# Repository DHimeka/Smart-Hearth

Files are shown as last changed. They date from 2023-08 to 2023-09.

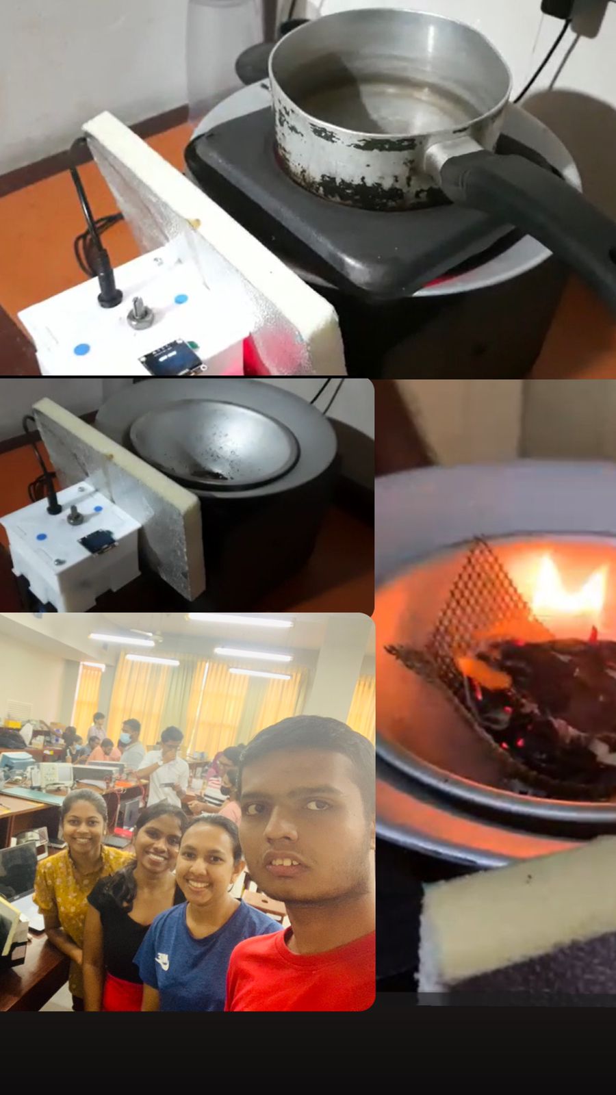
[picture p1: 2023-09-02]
images/Intro.jpg

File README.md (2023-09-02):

# Smart Hearth Project 

Smart Hearth Logo

In the EN2091 Laboratory Practice and Projects during our third semester, our team successfully designed and developed a fully functional function generator with laboratory-grade capabilities. By harnessing the potential of basic electronic components, we achieved precise waveform generation and control using opamps, transistors, resistors, capacitors, and potentiometers. Our research and design enabled the implementation of analog electronic calculations, resulting in the generation of sine, square, triangular, sawtooth, and PWM waveforms with accurate frequency control from 20Hz to 20kHz. A crucial aspect of the project was robust control over amplitude and DC, which we accomplished through feedback mechanisms and precise opamp configurations, allowing users to manipulate output voltage from 0V to 20V. Despite facing various challenges during the project, including iterative circuit refinement and enclosure and PCB fabrication, the final outcome was impressive. The fully functional function generator showcased a harmonious fusion of creative circuit design and engineering to its finest. We take immense pride in this accomplishment, confident in the potential of our function generator to make a significant impact in laboratory settings and beyond.

## Table of Contents
- [Introduction](#introduction)
  - [Product Overview](#product-overview)
  - [Key Components](#key-components)
- [Development](#development)
  - [Circuit Design](#circuit-design)
  - [Arduino Implementation](#arduino-implementation)
  - [Breadboard Implementation](#breadboard-implementation)
  - [PCB Design](#pcb-design)
  - [Enclosure Design](#enclosure-design)
- [List of Components](#list-of-components)
- [UI and UX](#ui-and-ux)
- [Testing and Results](#testing-and-results)
- [Further Improvements](#further-improvements)
- [Discussions](#discussions)
- [Bibliography](#bibliography)

## Introduction

### Product Overview

The Smart Hearth project is designed to address the challenges faced by households relying on traditional hearths for cooking. It introduces a system that automates temperature regulation, improving the cooking experience and reducing user intervention. The core components of the device include the ATmega328P microcontroller, MAX6675 Temperature Sensor, OLED display, potentiometer, DC fan, and more.

### Key Components

- **ATmega328-PU:** This high-performance microcontroller forms the heart of the system, controlling various aspects of the Smart Hearth's functionality.

- **MAX6675 Temperature Sensor:** Responsible for accurately measuring the temperature of the hearth, ensuring precise control.

- **OLED Display:** Provides users with real-time information about the selected temperature range and system status.

- **Potentiometer:** Enables users to choose from six predefined temperature ranges, enhancing user-friendliness.

- **DC Fan:** Regulates the heat by adjusting its speed based on the temperature sensor readings.

## Development

### Circuit Design

The project began with circuit design using the EasyEDA software, ensuring the proper connections among components. The schematic design encompassed various elements, including temperature sensors, microcontrollers, and motor driver modules.

### Arduino Implementation

The initial implementation involved testing the circuit with LED bulbs to assess brightness control based on temperature levels. Subsequently, a DC fan was integrated into the circuit, followed by the addition of a buzzer to alert users of abnormalities. The OLED display was also incorporated to visualize temperature settings.

### Breadboard Implementation

To move from Arduino testing to a standalone system, the circuit was replicated on a standalone ATmega328-PU microcontroller. This step ensured the transition to a more compact and functional setup.

### PCB Design

Altium software was used for designing a single-layer PCB, considering factors like trace width and power requirements. The design aimed to optimize the circuit layout for efficient performance.

### Enclosure Design

The physical enclosure for the Smart Hearth underwent careful consideration. A conical shape was chosen for the hearth's opening to facilitate efficient heat transfer. Aluminum was selected as the primary material for its durability and resistance to cracking. A wooden box surrounded the aluminum structure to prevent user harm from the heated material. The design also featured openings for the fan, LCD, potentiometer, and temperature sensor.

## List of Components

- **ATmega328-PU:** The microcontroller at the heart of the system.
- **MAX6675 Temperature Sensor:** Responsible for precise temperature measurements.
- **OLED Display:** Provides real-time information to users.
- **Potentiometer:** Enables user selection of temperature ranges.
- **DC Fan:** Regulates heat by adjusting speed.
- **L9110 Motor Driver Module:** Controls the fan's speed.
- **12V Power Pack:** Provides power to the system.

## UI and UX

The user interface consists of an OLED display and a potentiometer. Users can select from six temperature ranges, each represented by a specific color on the potentiometer. The selected range is displayed on the OLED, making it easy for users to monitor and adjust settings.

## Testing and Results

Extensive testing was conducted to ensure the system's functionality. Individual component testing was performed using Arduino, including LED brightness control, fan speed adjustment, buzzer functionality, and OLED output validation. The system successfully regulated temperature within selected ranges.

## Further Improvements

Future enhancements to the Smart Hearth system could include:

- Smoke disposal system for improved air quality.
- Development of a mobile app for remote control and monitoring.
- Enhanced product packaging for user convenience and safety.

## Discussions

During development, several challenges were addressed, including:

- Material selection for the hearth enclosure.
- Overlapping OLED display terms.
- Determining the optimal time for the buzzer to activate.

## Bibliography

- [Guide for I2C OLED Display with Arduino](https://randomnerdtutorials.com/guide-for-oled-display-with-arduino/)
- [Spherical and Cylindrical Pressure Vessels](https://www.wermac.org/equipment/pressurevessel.html)
- [Getting Started With the ATMega328P](https://www.instructables.com/Getting-Started-With-the-ATMega328P/)
- [Temperature based Fan Speed Control](https://create.arduino.cc/projecthub/embeddedlab786/temperature-based-fan-speed-control-945f9d)
- [WHEN TO USE ALUMINUM VS STAINLESS STEEL](https://www.kloecknermetals.com/blog/when-to-use-aluminum-vs-stainless-steel/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,over%20steel%20in%20cold%20temperatures.)
- [The Laws of Thermo-Culinary Dynamics](https

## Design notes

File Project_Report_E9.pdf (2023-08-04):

## Department of Electronic & Telecommunication Engineering

## University of Moratuwa

# Hearth

### Group EN09

200222K | HIMEKA S.H.D.
200232P | INDRAPALA S.A.
200239T | JATHURSHAN S.
200242V | JAYAKODY J.A.A.U.

This report is submitted for module EN1190

07th October 2022

## Abstract

The hearth regulates the temperature of the fire as per the user requirement by using the reading taken from the temperature sensor and regulating the DC fan speed accordingly. The hearth has a user interface which allows the user to turn a knob to their required temperature range and the selected range will be displayed on the OLED. Additionally, the hearth also has a buzzer going off if there are any abnormalities when functioning. The enclosure for the hearth was designed using SolidWorks and attention was given to the materials employed. The PCB was designed using Altium.

## Contents

### Introduction

The hearth takes into consideration the input temperature range by the user as well as the
current | temperature | reading | from | the
temperature sensor and will change the fan speed in order to bring the temperature into the users’ temperature range. The main components of the device are,
- ATmega328P-PU
- MAX6675 Temperature Sensor
- OLED
- 100K Potentiometer
- 12V DC fan
- L9110 Motor Driver Module
- 12V Power Pack

The device gives the user an option of 6 temperature ranges and has a buzzer and a display to notify the user of the selected temperature range and if there is an issue in the functionality.

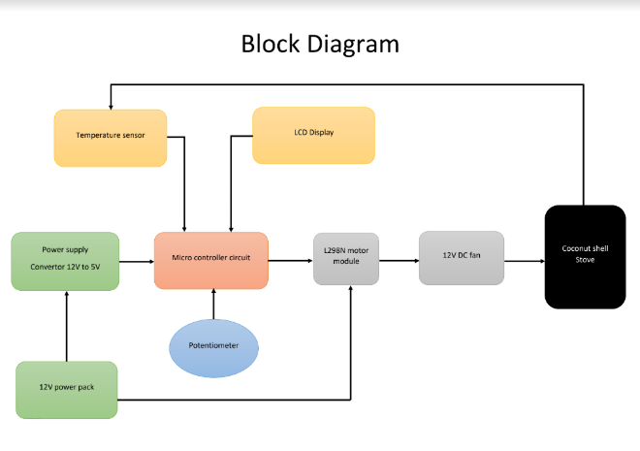
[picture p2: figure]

Figure 1.1: Block Diagram of the Device

### Product Description

Design Idea

Given the shortage of gas cylinders and the hike of gas cylinder prices in the recent past in Sri Lanka, most people have been turning to using electric induction cookers or hearths. Since electricity prices as well as induction cooker prices have also increased, most households have been using traditional hearths.

Motivation

However, these hearths have potential to be improved to make the cooking experience more user friendly. The existing market products can be seen to lack the following features,

- User must keep blowing into the flame to control the flame. Even the hearths with DC fans have an unreliable increase and reduction in temperatures such that the user must consistently be present to adjust fan speeds.
- Soot depositions on cooking utensils and the stove.
- Cleaning the ash leftovers after usage.
- Smokes released are disturbing.

Who Benefits?

Our device would cater to most lower to middle class households as it could reduce the costs associated with gas cylinders as well as electricity.

### Product Idea Validation

Hearths have a lot of room for improvement. However, the main problem we chose to focus on was the fact that the user must be in constant vicinity of the hearth to ensure that the heat from the fire is regulated at the needed level. This would be a waste of time for the consumer.

Therefore, our solution was to build a hearth with a DC fan which would regulate the heat in the needed level once the user has input their requirement.

To ensure that this was a requirement of our target market we conducted a survey through which we collected the following data.

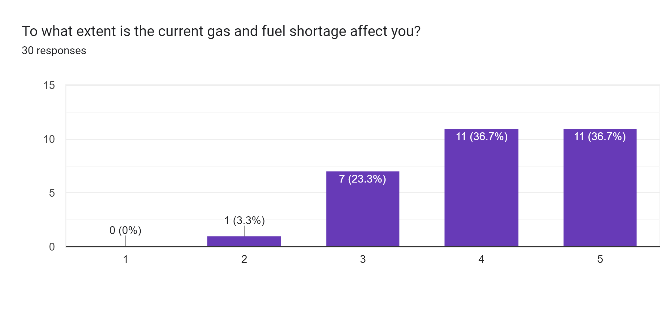
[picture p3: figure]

Figure 3.1: The extent to which users were affected by the gas shortage.

As seen by Figure 3.1, more than 50% of users were highly affected by the gas shortage. Therefore, an alternative for gas cookers is necessary.

Figure 3.2: Will the user buy our product?

On explaining the product, we had in mind, most users showed positive responses whereas a few were unsure but none of the users believed that the product was not needed.

Figure 3.3: User needs.

We then took this opportunity to check what the user expected of this product and on designing the product we took into consideration most of these factors.

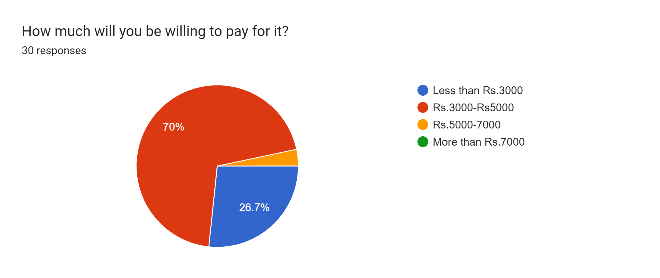
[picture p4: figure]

Figure 3.4: Product cost

Finally, we asked the users what cost they would be willing to incur for this product. As per Figure 3.4, the price range was determined to be between Rs 3,000 and Rs 5,000. However, this survey was conducted approximately 2 months prior and did not take into consideration the import bans as well as the inflation. Currently, the market price for similar products range between Rs 7,000 and Rs 11,000. Therefore, the price for the product may have to be reconsidered to around Rs 8,000 or more.

### Development

The development of this project was done in four stages. They are,

1. Circuit Design
2. Arduino Implementation
3. Breadboard Implementation with the

Microcontroller

Circuit Design

Initially a schematic with all the circuit components was built using the EasyEDA software. Afterwards, the connections between each component were made.

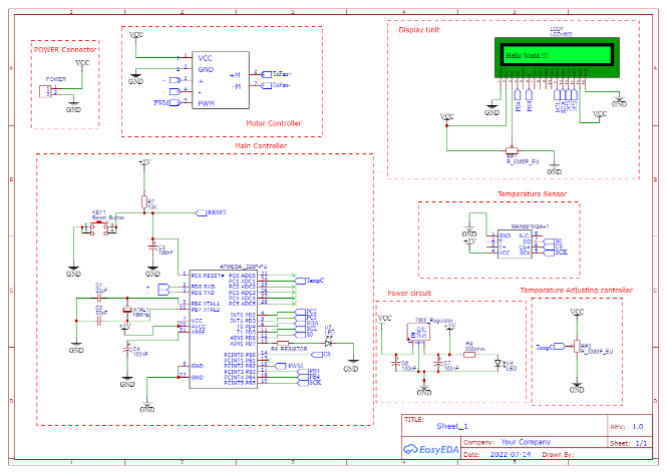
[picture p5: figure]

Figure 4.1: Circuit components

Arduino Implementation

Once all the circuit connections were made, the circuit was implemented on an Arduino step by step to check its functionality.

Initially, instead of using a DC fan, we placed LED bulbs in order to check whether the brightness can be changed for different temperature levels.

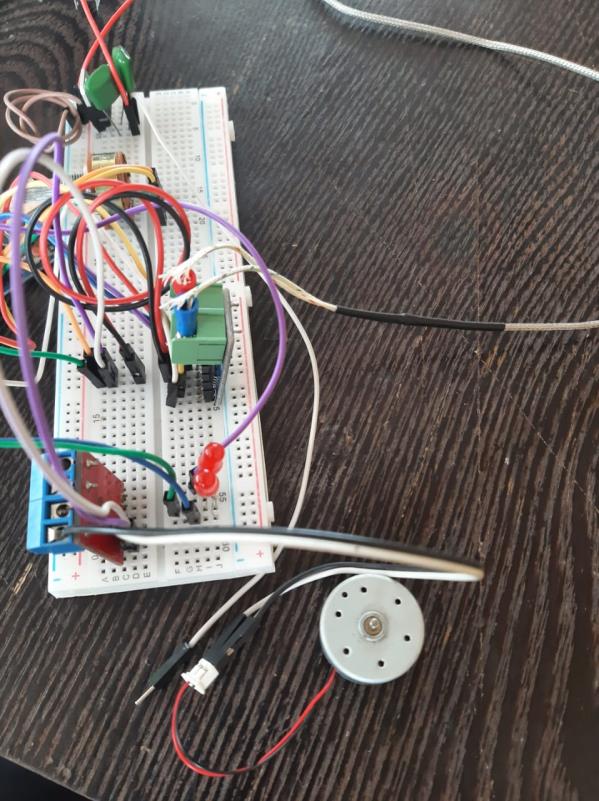
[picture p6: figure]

Figure 4.2: Testing using LED’s

After this proved to be successful, we next added the DC fan to the circuit as well.

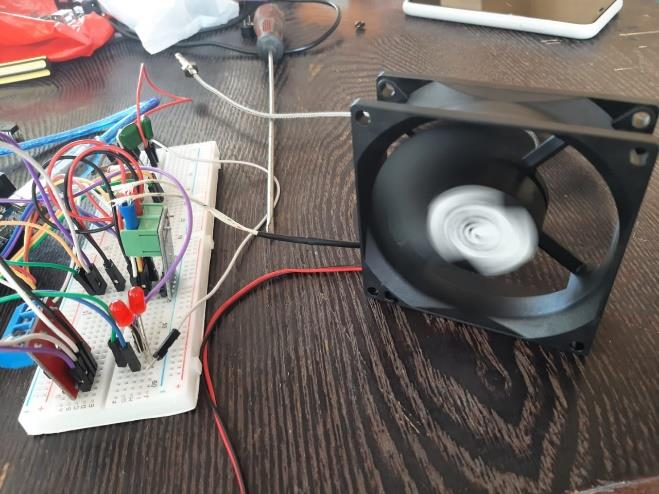
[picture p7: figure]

Figure 4.3: Testing the fan

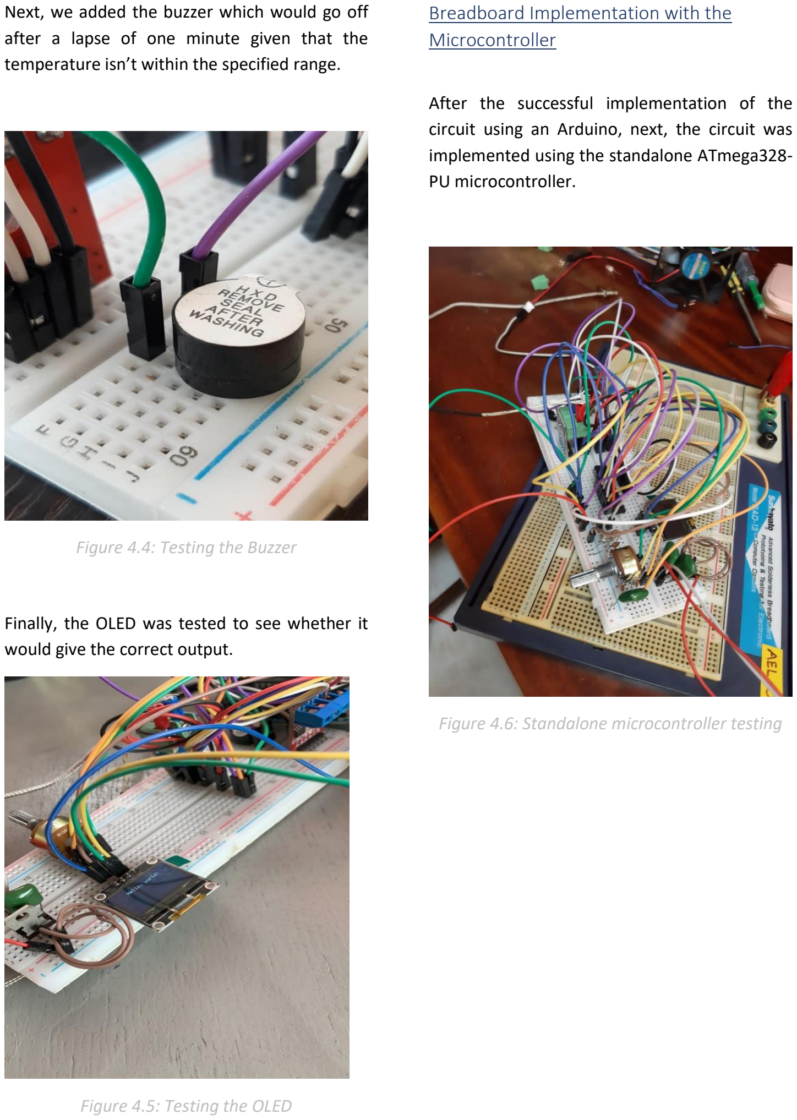
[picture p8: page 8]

Next, we added the buzzer which would go off after a lapse of one minute given that the temperature isn’t within the specified range.

Figure 4.4: Testing the Buzzer

Finally, the OLED was tested to see whether it would give the correct output.

Figure 4.5: Testing the OLED

Breadboard Implementation with the Microcontroller

After the successful implementation of the circuit using an Arduino, next, the circuit was implemented using the standalone ATmega328-PU microcontroller.

Figure 4.6: Standalone microcontroller testing

### PCB Design

PCB design was done using Altium software. In the schematic design, all the components and connections were done according to our circuit design and Arduino implementation. The design was a single layer PCB.

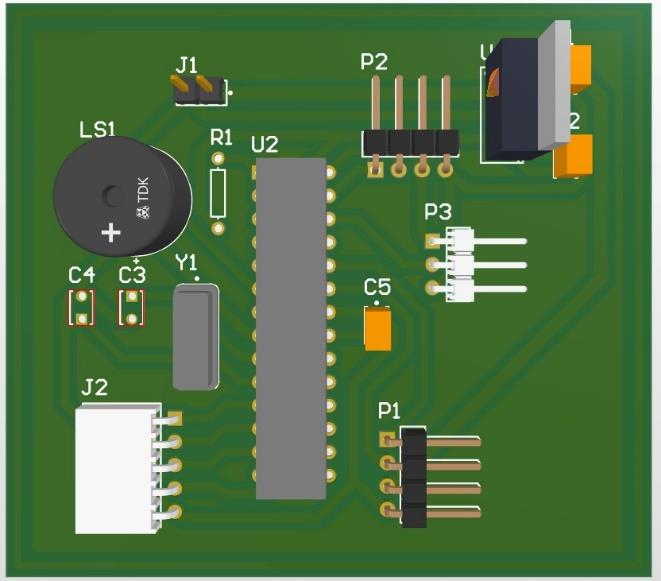
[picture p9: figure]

Figure 5.1: 3D view of the PCB

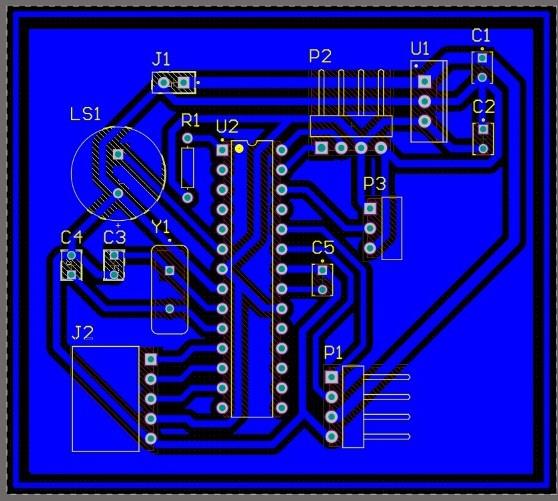
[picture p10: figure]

Figure 5.2: PCB design

For the 12V power supply 1.5mm trace width was selected and for the 5V power supply 1mm trace width was selected. The ground had a 1.5mm trace width and the signal lines had a 0.8mm trace width.

These measurements were made taking into
consideration | the | power | and | current
consumption of the circuit.

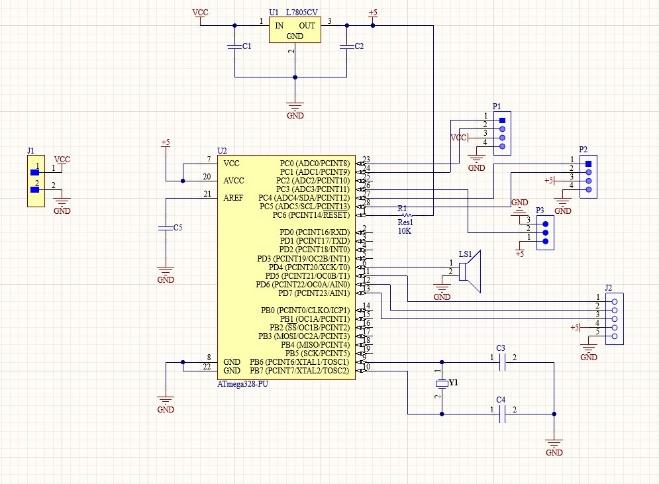
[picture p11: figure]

Figure 5.3: Schematic

### Enclosure Design

Considering the existing models in the industry, we made an initial sketch on how we wanted the hearth to look like.

To ensure that the cooking pots fit perfectly and to ensure efficient heat transfer, the opening of the hearth was decided to be conical in shape.

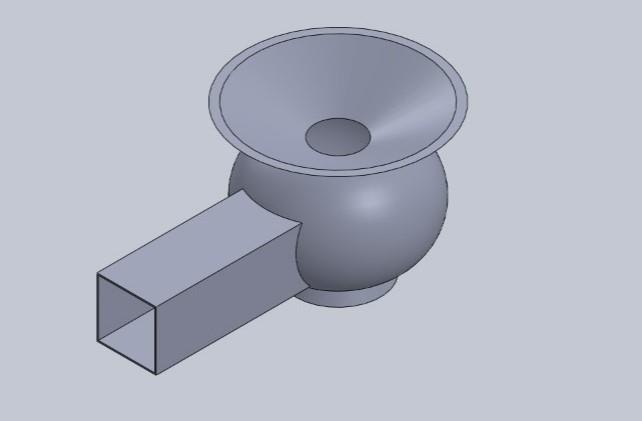
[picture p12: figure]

Figure 6.1: Hearth Enclosure

A spherical structure was selected for the base of the hearth as it would be a stronger structure than a cylindrical base.

It was decided that this structure should be made using aluminium as it would pose less of a risk than normal clay pots which are susceptible to cracking. Since aluminium tends to heat up and could be harmful to the user, it was decided that a wooden box should surround the aluminium structure.

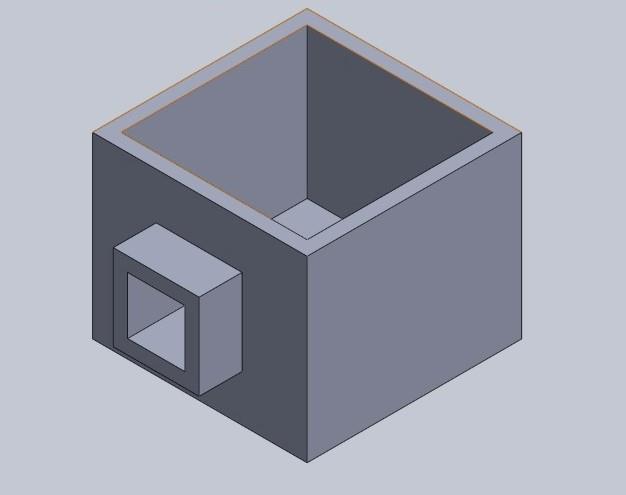
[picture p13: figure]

Figure 6.2: Wooden Enclosure

An opening was also made on the Aluminium structure to which the fan was attached. This structure had an opening at the end so that the fan had sufficient access to the atmosphere.

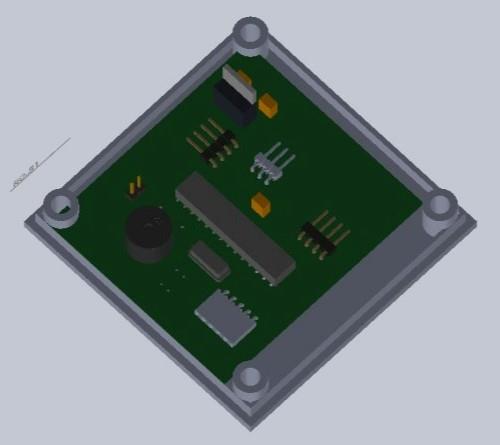
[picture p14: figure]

Figure 6.3: PCB Enclosure

Figure 6.4

Figure 6.5

On top of the fan enclosure the PCB enclosure was attached, and this enclosure was made taking into consideration the PCB design.

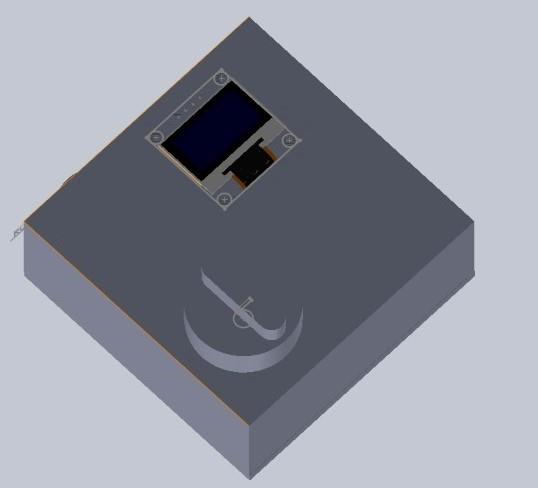
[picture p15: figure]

Figure 6.6: Top view of the PCB enclosure

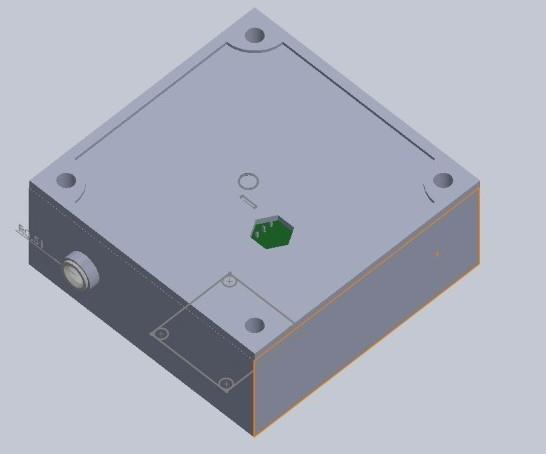
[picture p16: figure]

Figure 6.7: Bottom view of the PCB enclosure

For the PCB enclosure, 2 openings had to be made on top to accommodate the LCD as well as the potentiometer by which the user can choose the temperature range. Another opening was required at the bottom of the enclosure to connect the fan as well as to accommodate the temperature sensor.

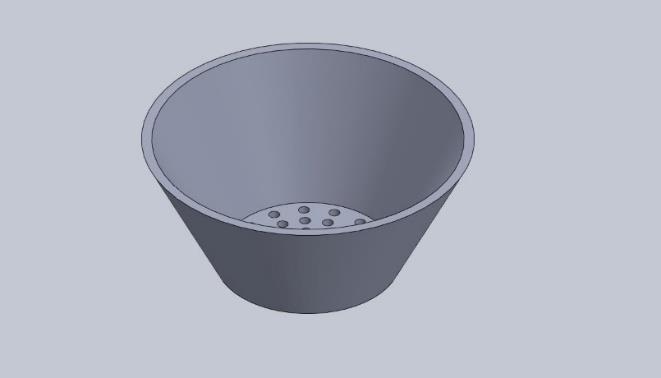
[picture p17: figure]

Figure 6.8: Removable opening in the enclosure

One user requirement was to make the removal of coconut husks easy. Therefore, another enclosure was placed at the opening to easily remove and replace and holes at the bottom to ensure that wind still passed through. To protect this enclosure from coconut husks, a mesh was

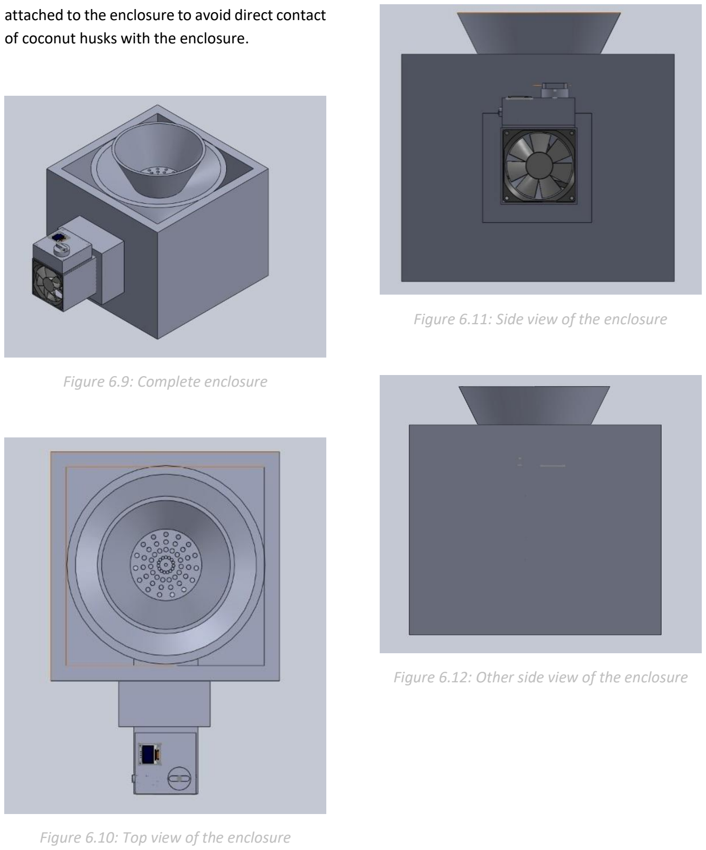
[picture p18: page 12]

attached to the enclosure to avoid direct contact of coconut husks with the enclosure.

Figure 6.9: Complete enclosure

Figure 6.10: Top view of the enclosure

Figure 6.11: Side view of the enclosure

Figure 6.12: Other side view of the enclosure

### List of Components

Component | Quantity
ATmega328-PU | 1
L7805CV | 1
100 nf capacitor | 3
22 pf capacitor | 2
16 MHz crystal oscillator | 1
Piezoelectric buzzer | 1
10K resistor | 1
2 pin headers | 1
4 pin headers | 2
3 pin headers | 2
5 pin headers | 1
230V-12V Power regulator | 1
MAX6675 Temperature sensor | 1
L9110 Motor module | 1
12V DC fan | 1
OLED | 1
100K Potentiometer | 1

ATmega328-PU

The high-performance Pico Power 8bit AVR RISCbased microcontroller combines 32KB ISP flash memory with read-while-write capabilities, 1024B EEPROM, 2KB SRAM, 23 general purposes I/O lines, 32 general purpose working registers, three flexible timer/counters with compare modes, internal and external interrupts, serial programmable USART, a byte-oriented 2-wire serial interface, SPI serial port, a 6-channel 10-bit A/D converter (8-channels in TQFP and QFN/MLF packages), programmable watchdog timer with internal oscillator, and five software selectable power saving modes. The device operates between 1.8-5.5 volts. This is the main component of the microcontroller circuit. Program is coded and fetched into this.

MAX6675 Temperature Sensor

The | MAX6675 | performs | cold-junction
compensation and digitizes the signal from a type-K thermocouple. The data is output in a 12-bit resolution, SPI-compatible, read-only format. This converter resolves temperatures to 0.25°C, allows readings as high as +1024°C, and exhibits thermocouple accuracy of 8 LSBs for temperatures ranging from 0°C to +700°C. The MAX6675 is available in a small, 8-pin SO package.

Figure 7.1: Temperature Sensor

Considering the components used, the existing products in the market as well as the enclosure, we determined that our product lifetime is 3 years.

L9110 Motor Driver Module

L9110 Module can control up to 2 DC motors with directional and speed control. Previously we had selected the L298 Motor Driver Module however it has a higher power consumption. Therefore, we chose to switch to this motor driver module instead.

This is used to control the speed of the 12V DC fan.

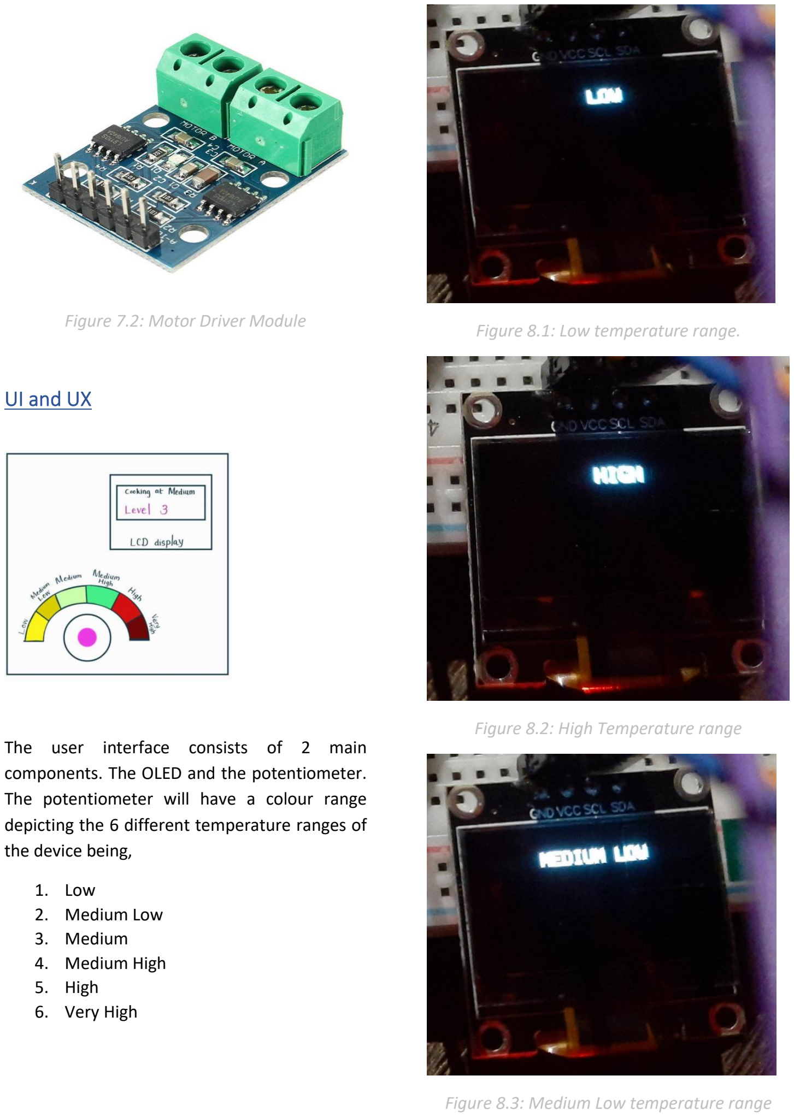
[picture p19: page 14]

Figure 7.2: Motor Driver Module

### UI and UX

The user interface consists of 2 main components. The OLED and the potentiometer. The potentiometer will have a colour range depicting the 6 different temperature ranges of the device being,

1. Low
2. Medium Low
3. Medium
4. Medium High
5. High
6. Very High

Figure 8.1: Low temperature range.

Figure 8.2: High Temperature range

Figure 8.3: Medium Low temperature range

Once one of these ranges are selected by the potentiometer, the output will be shown on the OLED.

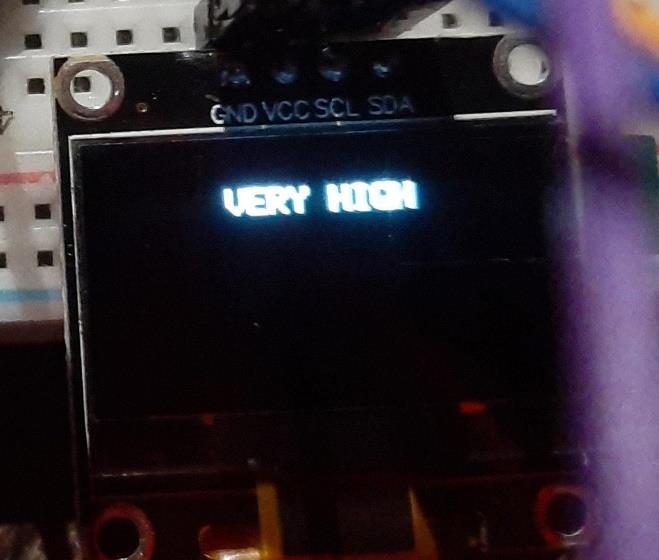
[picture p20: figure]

Figure 8.4: Very High temperature range

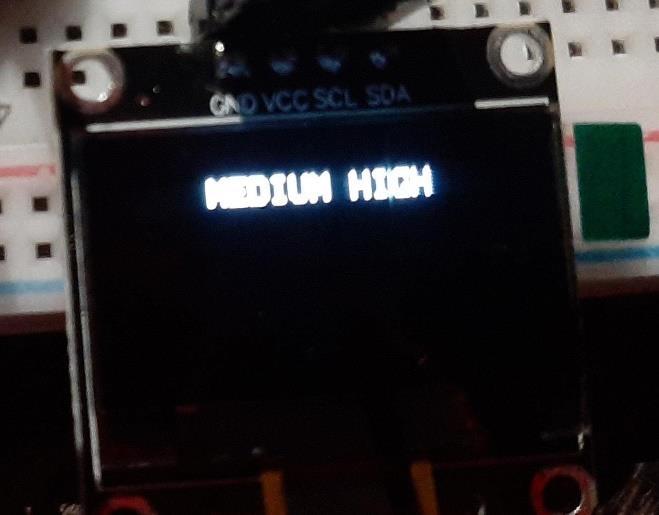
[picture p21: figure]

Figure 8.5: Medium High temperature range

### Testing

To ensure the functionality of the system, several tests were conducted both for individual components as well as the entire system. The tests conducted are as follows,

- Individual testing of the component

functionality using Arduino (mentioned

above).

- Testing the heat tolerance of the hearth

enclosure (Mentioned below).

- Testing the fan speeds for different

temperature ranges by hardcoding input

temperatures from the sensor.

- Testing buzzer functionality by hard

coding erroneous values.

- Checking different temperature ranges

for different potentiometer inputs. This

was also used to check whether the

OLED was displaying the correct outputs.

- Testing whether the temperature sensor

was giving correct outputs by using 2

different temperature sensors.

### Results

When the device is initially switched on, the LCD will display “Hello. Choose a Temperature Range.” Then the user will have to turn the knob to one of the 6 temperature ranges specified on the enclosure.

Once a temperature range is selected, the LCD will display the selected temperature range. Meanwhile, the temperature sensor will read the current temperature of the coconut husks and will switch on the DC fan to a specified speed to bring the temperature to the selected level.

If the temperature is too high, the fan will switch off and the temperature will drop and once it drops past the selected temperature level, the fan will restart.

In the case that there are some unforeseen circumstances, and the temperature remains too high despite the fan being turned off, the buzzer will go off after a lapse of 1 minute. Similarly, if the temperature doesn’t increase despite the fan being turned on, the buzzer will go off again after a lapse of one minute.

### Further Improvements

The device can be further improved to accommodate other user requirements such as,

- A system to effectively dispose of the

smoke accumulated from the hearth.

- Creating an app so that the user can

complete the same tasks through the

app and get notifications for abnormal

functionality.

### Marketing and Sales

Product Packaging

Since the product is not fragile nor does it have any technical specifications for storage, packaging can be done using a normal cardboard box with bubble wrap. A leaflet will also be given with instructions on how to use the hearth.

Maintenance and repair

The warranty period for the hearth will be a period of 3 years and for any issues after sale services will be provided through either repair of the existing hearth or replacing it with a new hearth.

Disposal

Some components, such as the aluminium can be reused or recycled at the end of the product lifetime and therefore ways in which it can be reused will be mentioned on the leaflet. However, other electronic components will have to be disposed of in a safe manner and instructions for disposal will be given to the user in the leaflet.

### Discussions

Determining the material of the hearth.

A main concern when determining the material of the hearth was the melting point or cracking point of the material. Using clay for the pot would mean that the pot would crack at our maximum temperatures but there was also a concern as to whether aluminium would melt at our highest temperature range. Therefore, the material was tested by holding it to a high flame and observing its’ results. No negative results were observed.

OLED display terms were overlapping.

When changing the temperature range from one user input to another, the display would overlap the terms for a period of 2 seconds before completely changing. This was because the outputs were of different sizes and therefore for a complete rewrite of the output, padding needed to be added so that all outputs were of the same size.

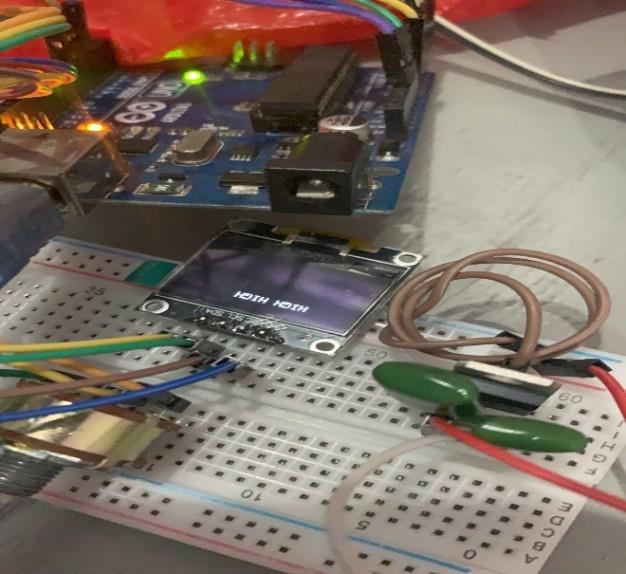
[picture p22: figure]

Figure 10.1: An overlap of “VERY HIGH” with “HIGH”

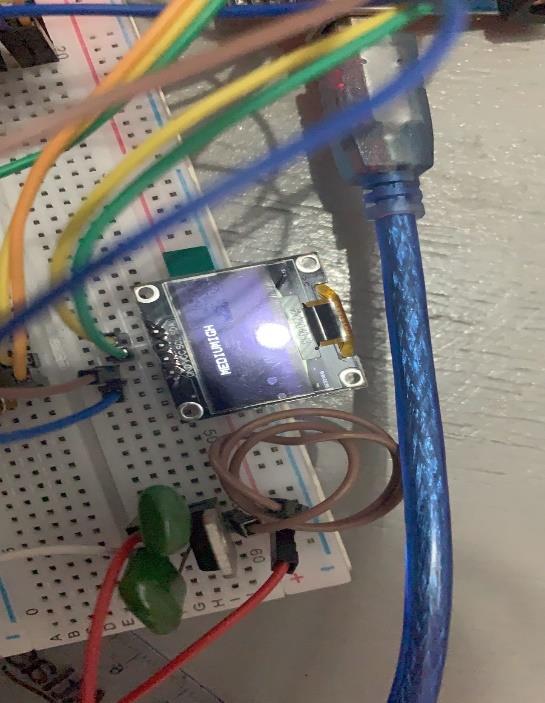
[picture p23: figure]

Figure 10.2: An overlap of “MEDIUM” with “HIGH”

Determining the count for the buzzer.

The buzzer is said to go off at the time of an issue. But we needed to determine the time needed for the buzzer to go off. Our code gets temperature readings every one second. To move the temperature from one range to another it would take some time and the time taken would depend on many factors. Through testing we determined that the best possible time lapse to wait until the buzzer goes off is 10 minutes as some temperature range shifts would take this amount of time whereas if there was an issue, a 10-minute lapse won’t be too disastrous.

### Acknowledgement

We would like to extend our gratitude to our lecturers who provided us with the required technical knowledge and guidance which served as the foundation for this project.

### Bibliography

Guide for I2C OLED Display with Arduino. Retrieved from

https://randomnerdtutorials.com/guide-foroled-display-with-arduino/ (https://randomnerdtutorials.com/guide-for-oled-display-with-arduino/)

Spherical and Cylindrical Pressure Vessels. Retrieved from

https://www.wermac.org/equipment/pressurev essel.html (https://www.wermac.org/equipment/pressurevessel.html)

Getting Started With the ATMega328P. Retrieved from

https://www.instructables.com/Getting-Started-With-the-ATMega328P/ (https://www.instructables.com/Getting-Started-With-the-ATMega328P/)

Temperature based Fan Speed Control. Retrieved from https://create.arduino.cc/projecthub/embeddedlab786/temperature-based-fan-speed-control-945f9d (https://create.arduino.cc/projecthub/embeddedlab786/temperature-based-fan-speed-control-945f9d)

WHEN TO USE ALUMINUM VS STAINLESS STEEL. Retrieved from

https://www.kloecknermetals.com/blog/whento-use-aluminum-vs-stainlesssteel/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 s%20steel%20vs,over%20steel%20in%20cold%2 0temperatures. (https://www.kloecknermetals.com/blog/when-to-use-aluminum-vs-stainless-steel/)

TODD OPPENHEIMER. The Laws of Thermo-Culinary Dynamics. Retrieved from

https://craftsmanship.net/sidebar/the-laws-ofthermo-culinarydynamics/#:~:text=Aluminum%20is%20even%2 0more%20aggressive,than%20its%20equivalent %20in%20clay. (https://craftsmanship.net/sidebar/the-laws-of-thermo-culinary-dynamics/)

Maureen. Induction Cooking Temperature Guide With Settings & Chart. Retrieved from

https://apreparedkitchen.com/inductioncooking-temperature-settings/ (https://apreparedkitchen.com/induction-cooking-temperature-settings/)

### Appendices

Budget

Component | Quantity | Cost
ATmega328-PU | 1 | 1700
L7805CV | 1 | 60
100 nf capacitor | 3 | 15
22 pf capacitor | 2 | 20
16 MHz crystal oscillator | 1 | 40
Piezoelectric buzzer | 1 | 240
10K resistor | 1 | 45
2 pin headers | 1 | 90
4 pin headers | 2
3 pin headers | 2
5 pin headers | 1
230V-12V Power regulator | 1 | 1380
MAX6675 Temperature sensor | 1 | 1350
L9110 Motor module | 1 | 200
12V DC fan | 1 | 620
OLED | 1 | 1000
100K Potentiometer | 1 | 60
PCB | | 550
Enclosure | | 2000
Total | | 9370

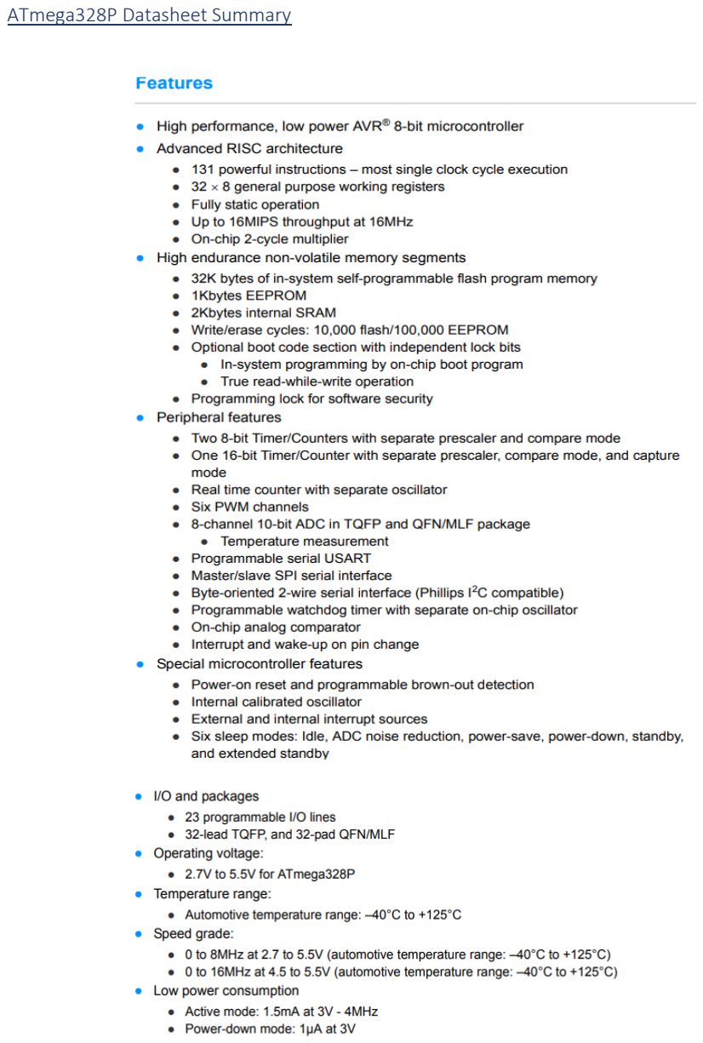
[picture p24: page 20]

ATmega328P Datasheet Summary

MAX6675 Temperature Sensor Datasheet Summary

Code

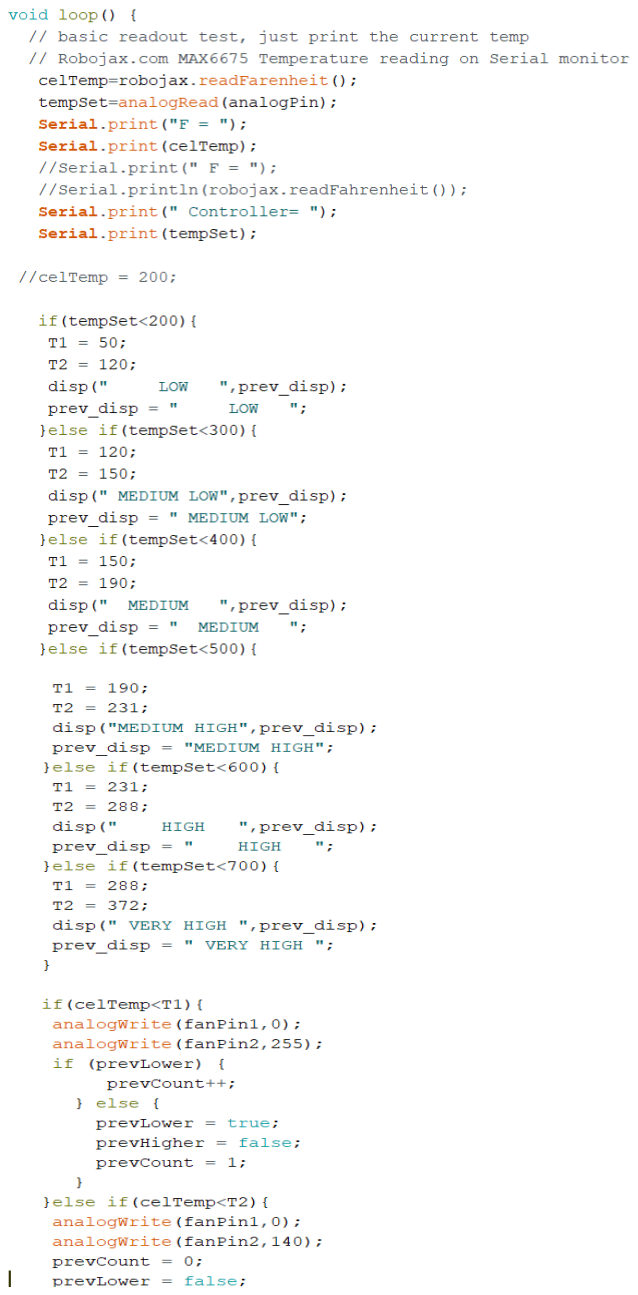
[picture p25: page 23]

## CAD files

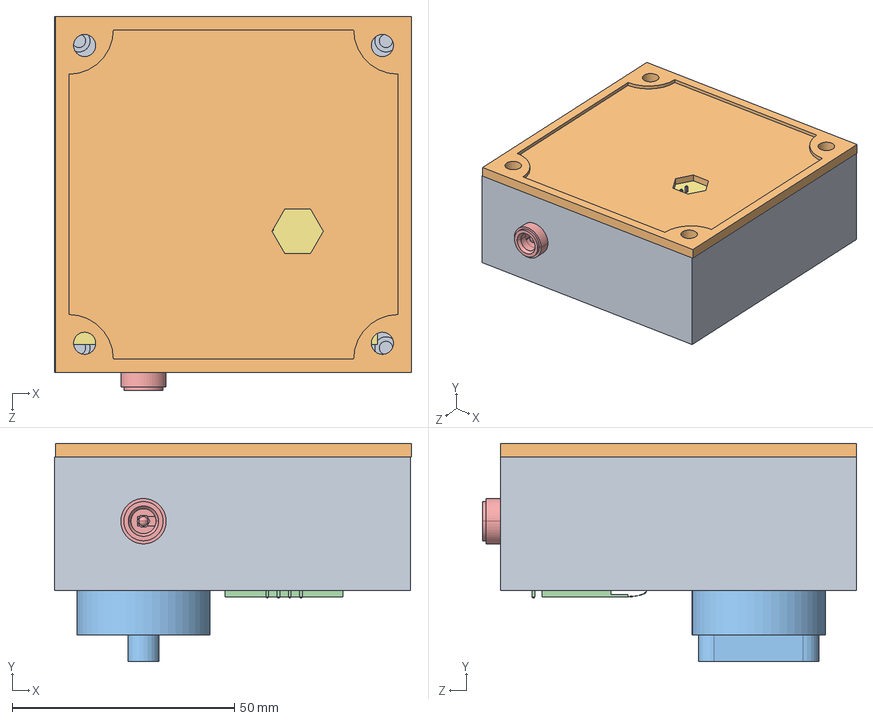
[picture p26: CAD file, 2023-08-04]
Solidworks Files/Solidworks/Ourbox.SLDASM
80.2 x 49.0 x 84.1 mm
Newupper
Newlower
User Library-128x64I2COLEDDisplayAdafruit
DC Jack Panel Mount Base.STEP
DC Jack Panel Mount Nut.STEP
Extruded.step
Extruded-0.step
Extruded-1.step
Extruded-2.step
Extruded-3.step
MTSW-103-08-X-S-229-RA.step
6130xx11021_PIN.step x 8
61300411021-4.step x 2
Body.step
Plus_Sign.step
TDK_Logo.step
SSQ-105-02-X-S-RA.step
TSW-102-07-L-S_body.step
T-1S6-07-TSW-1-07-2-S.step
Samtec.step
Extruded-5.step x 3

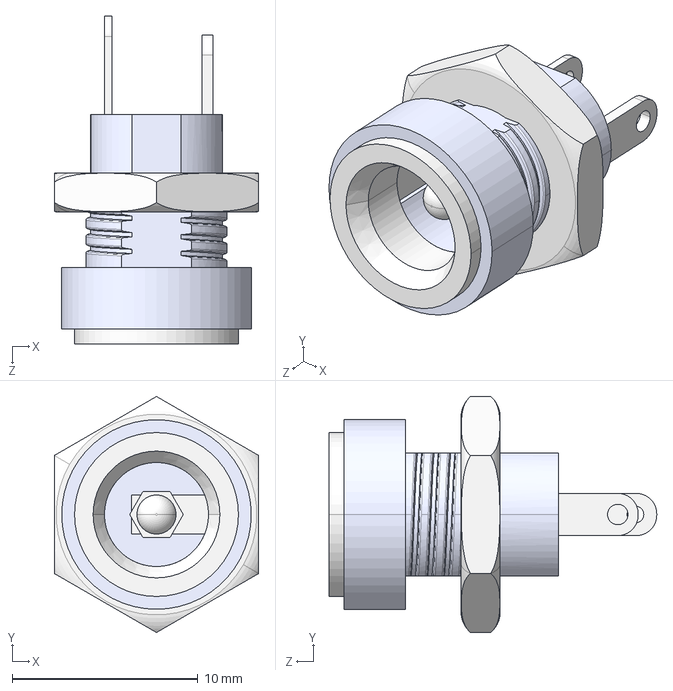
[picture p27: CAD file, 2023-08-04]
Solidworks Files/Solidworks/DC Jack Panel Mount ASSY.STEP
11.0 x 12.7 x 17.6 mm
DC Jack Panel Mount Base
DC Jack Panel Mount Nut

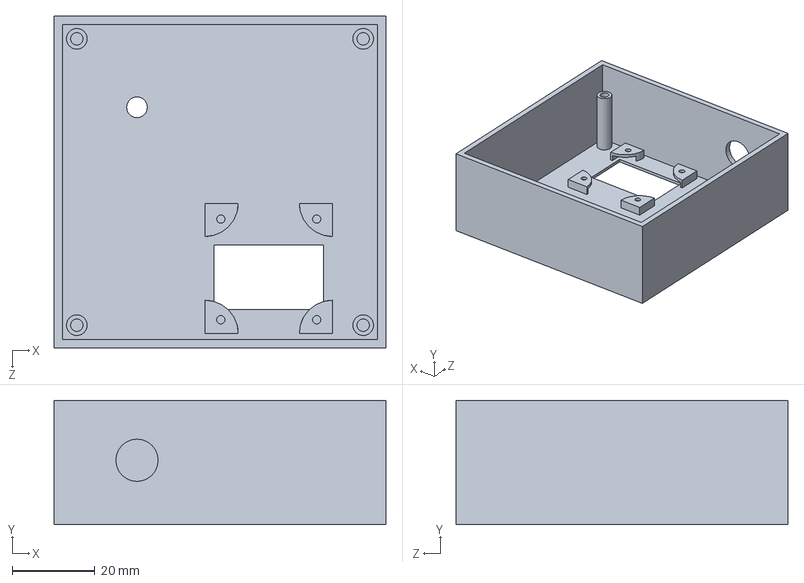
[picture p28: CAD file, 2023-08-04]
Solidworks Files/Solidworks/Newupper.SLDPRT
80.0 x 30.0 x 80.0 mm

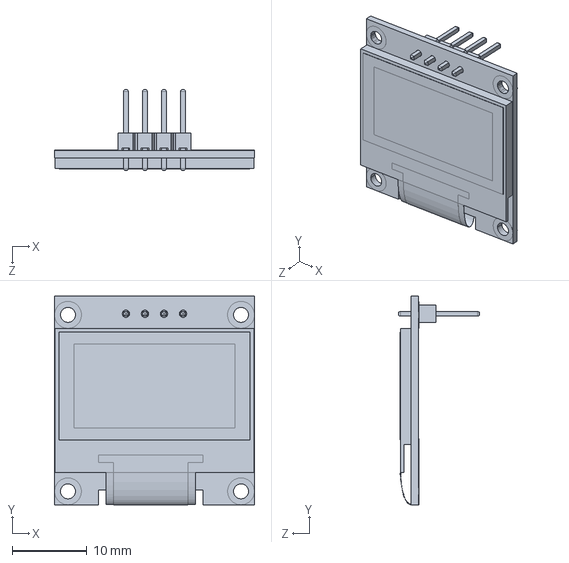
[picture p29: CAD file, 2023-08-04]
Solidworks Files/Solidworks/User Library-128x64I2COLEDDisplayAdafruit.sldprt
26.7 x 27.9 x 10.8 mm

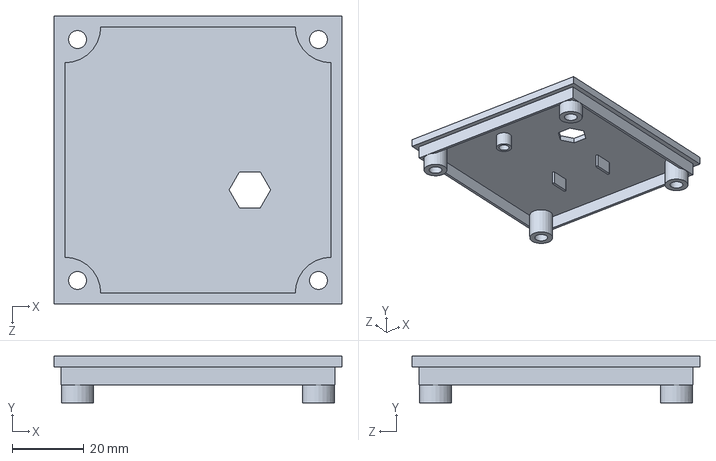
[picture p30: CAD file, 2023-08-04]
Solidworks Files/Solidworks/Newlower.SLDPRT
80.0 x 13.0 x 80.0 mm

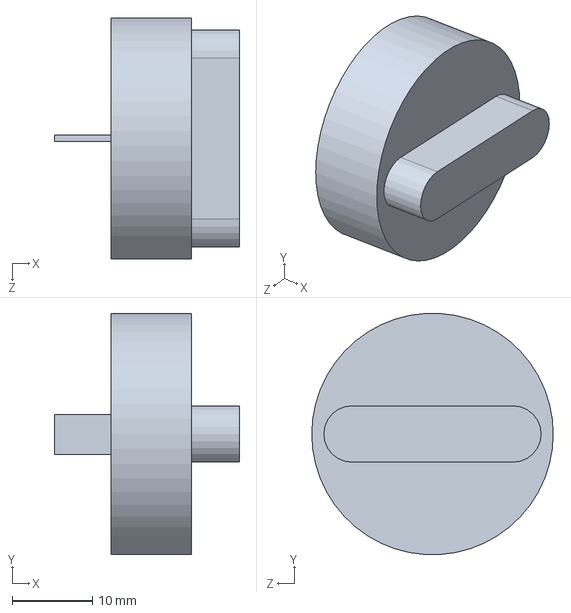
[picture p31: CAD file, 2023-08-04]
Solidworks Files/Solidworks/Part3.SLDPRT
23.0 x 29.9 x 30.0 mm

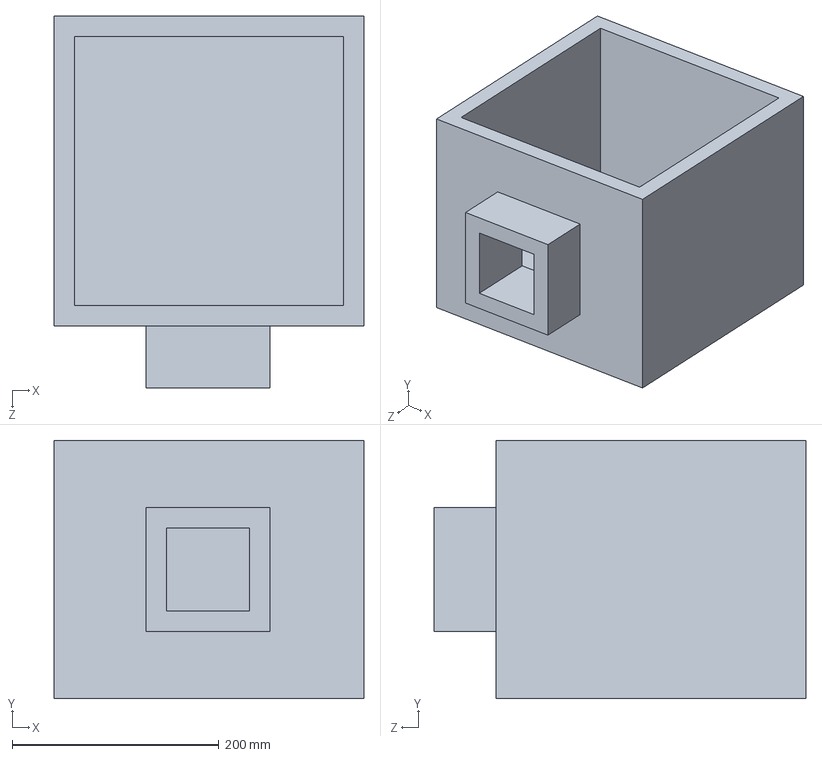
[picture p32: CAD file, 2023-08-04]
Solidworks Files/Solidworks/Box.SLDPRT
300.0 x 250.0 x 360.0 mm

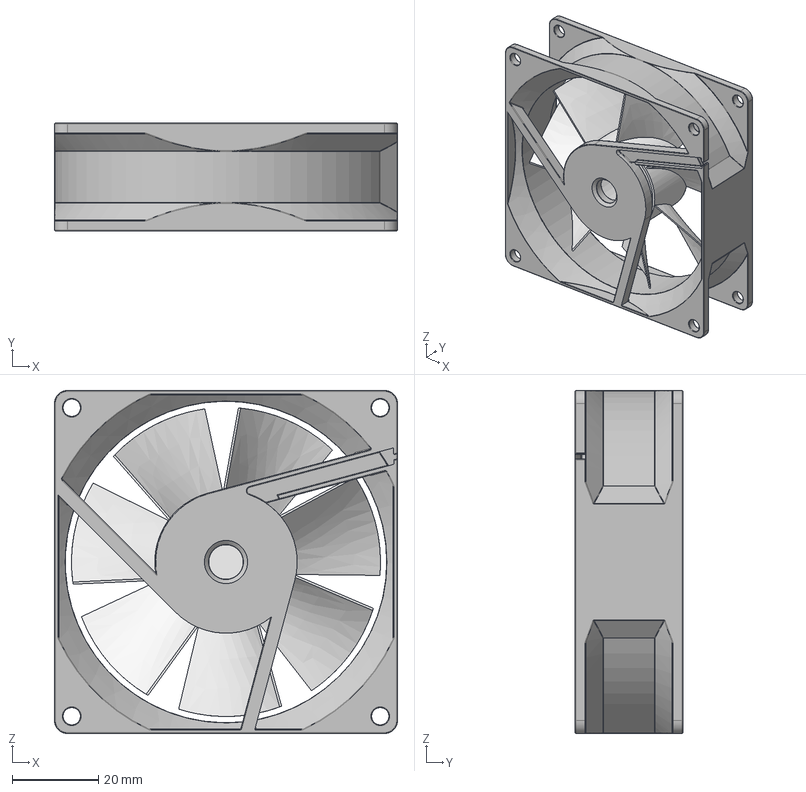
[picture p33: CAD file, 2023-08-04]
Solidworks Files/Solidworks/80MM_FAN.step
79.5 x 25.0 x 79.5 mm

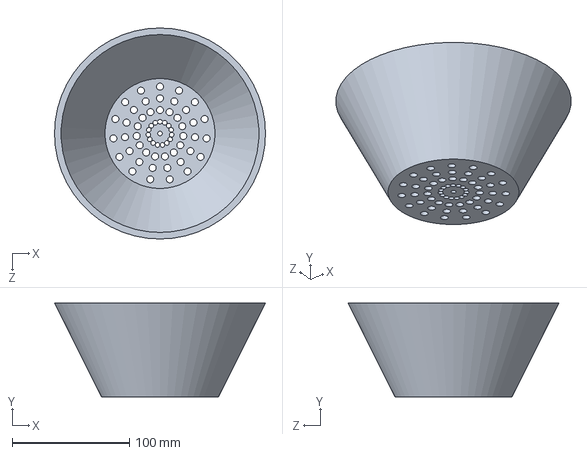
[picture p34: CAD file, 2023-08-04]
Solidworks Files/Solidworks/COAL.SLDPRT
180.0 x 80.0 x 180.0 mm

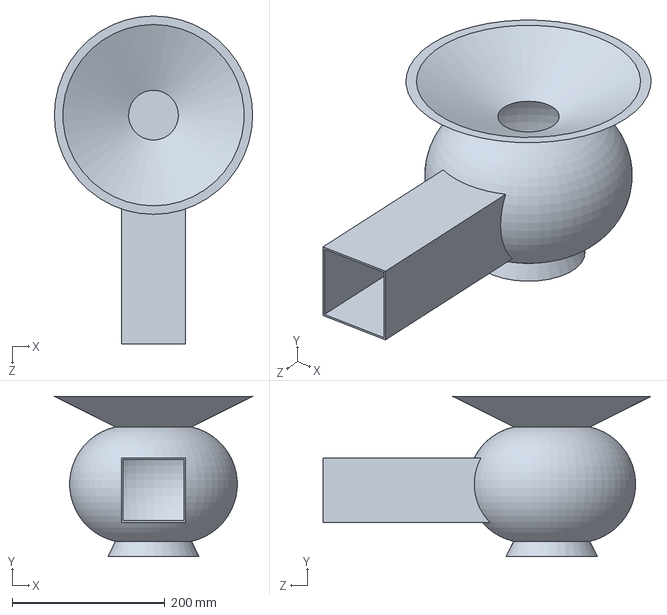
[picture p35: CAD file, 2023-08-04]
Solidworks Files/Solidworks/pOTNEW.SLDPRT
260.0 x 210.0 x 430.0 mm

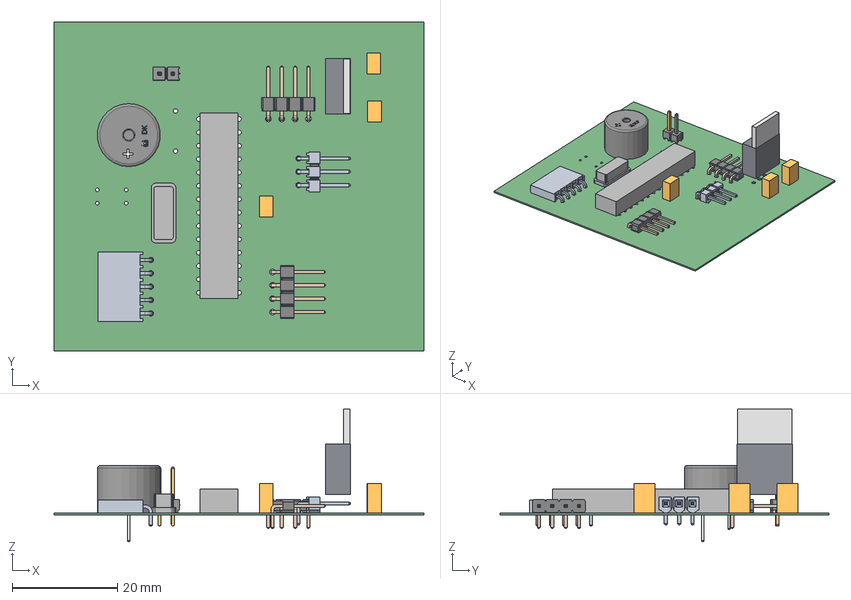
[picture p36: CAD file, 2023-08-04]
Solidworks Files/Solidworks/PCB3.step
70.4 x 62.5 x 25.2 mm
Extruded x 8
MTSW-103-08-X-S-229-RA
6130xx11021_PIN x 8
Plus_Sign
TDK_Logo
SSQ-105-02-X-S-RA
TSW-102-07-L-S_body
T-1S6-07-TSW-1-07-2-S
Samtec
C4
C3

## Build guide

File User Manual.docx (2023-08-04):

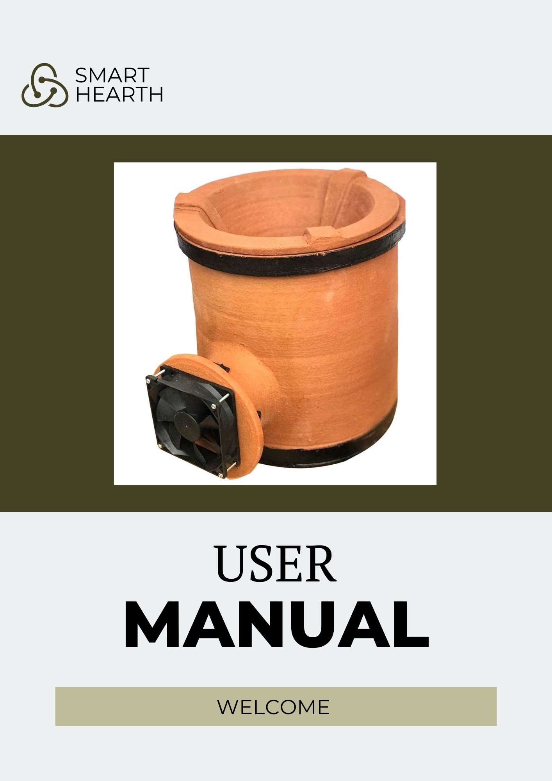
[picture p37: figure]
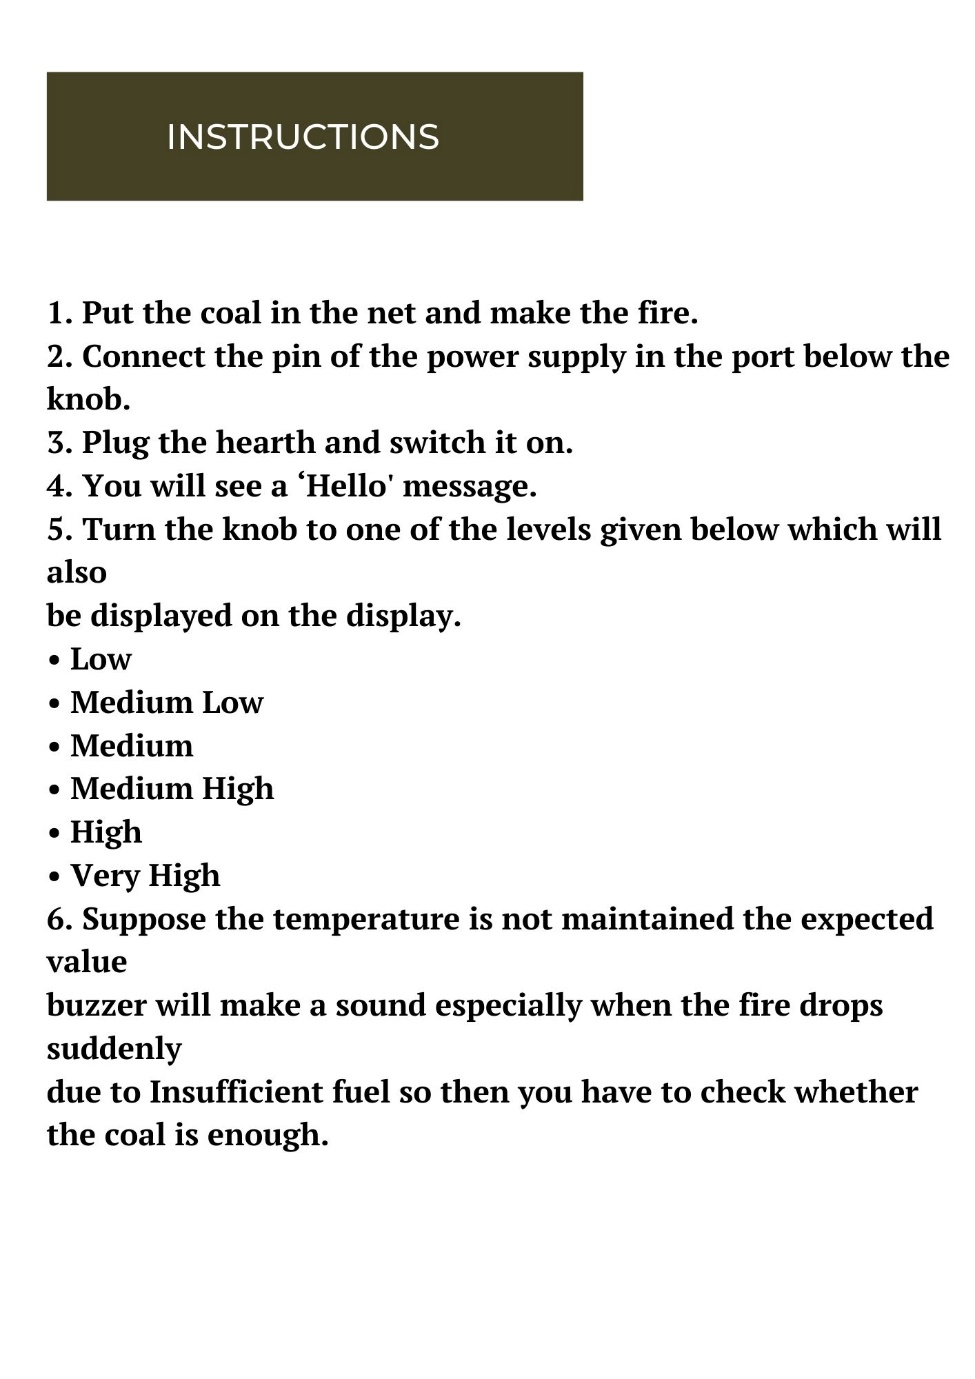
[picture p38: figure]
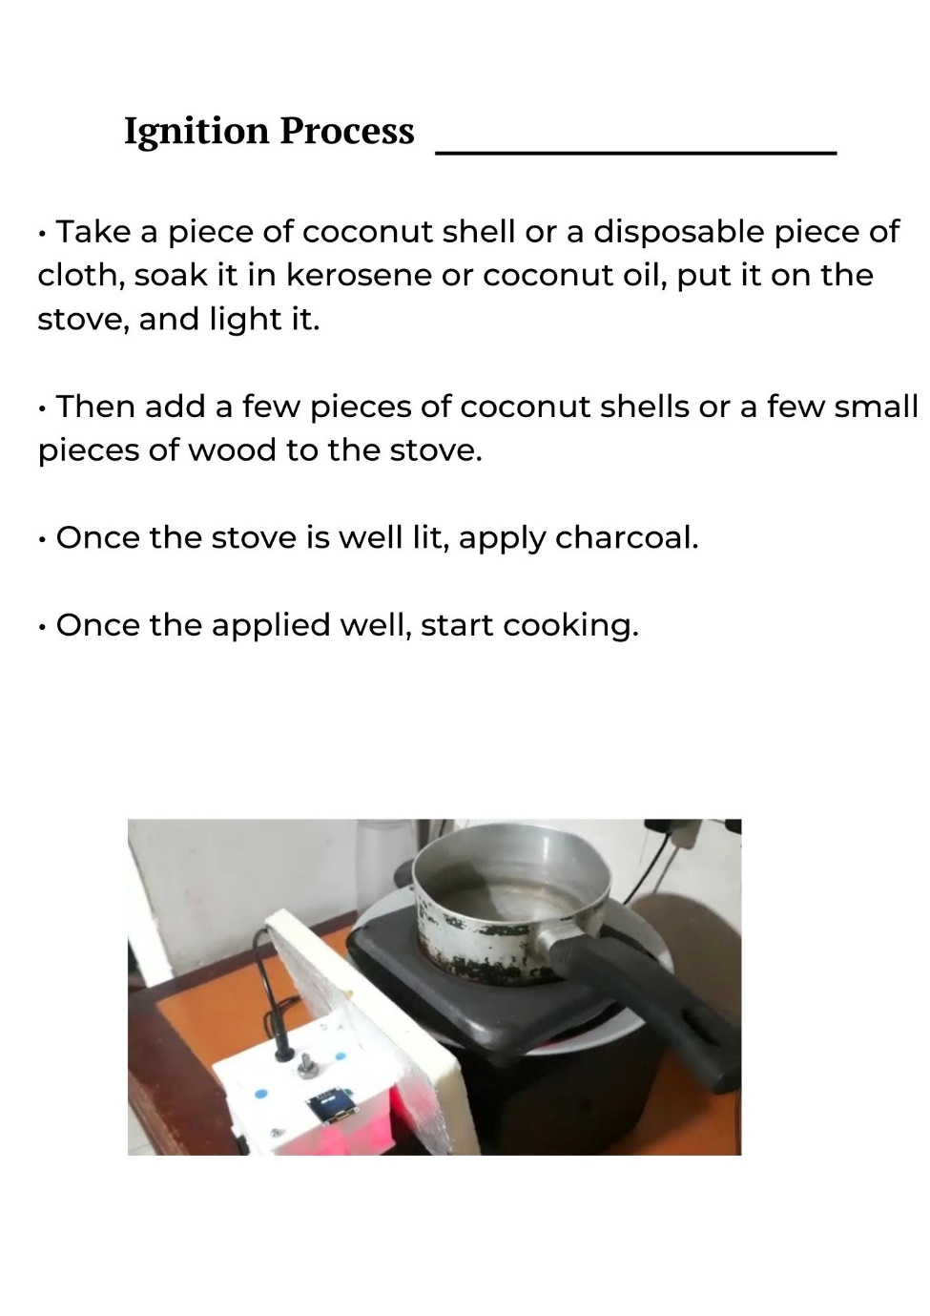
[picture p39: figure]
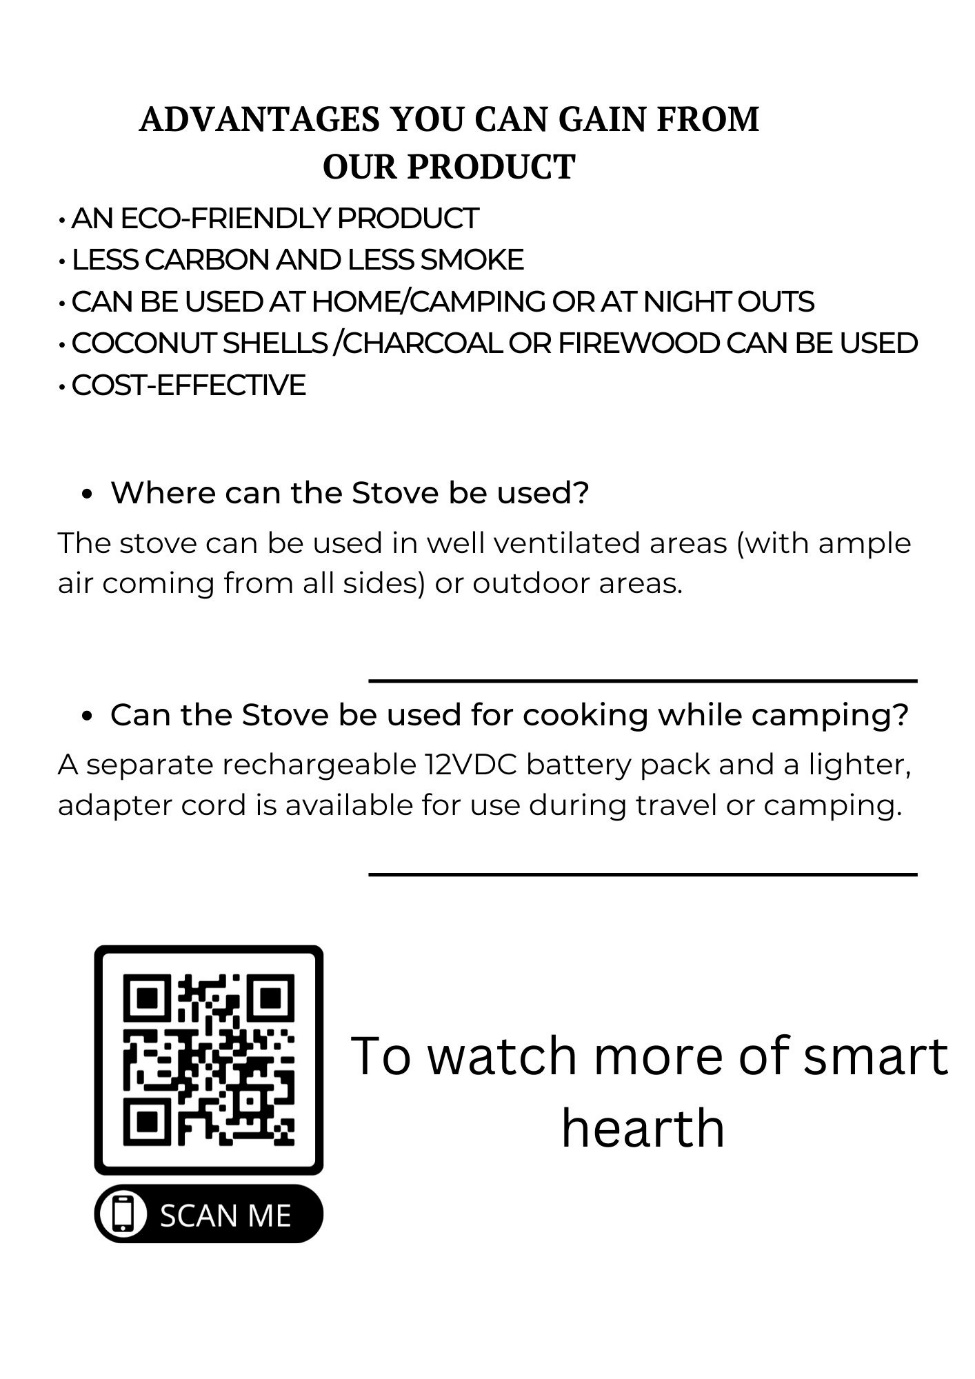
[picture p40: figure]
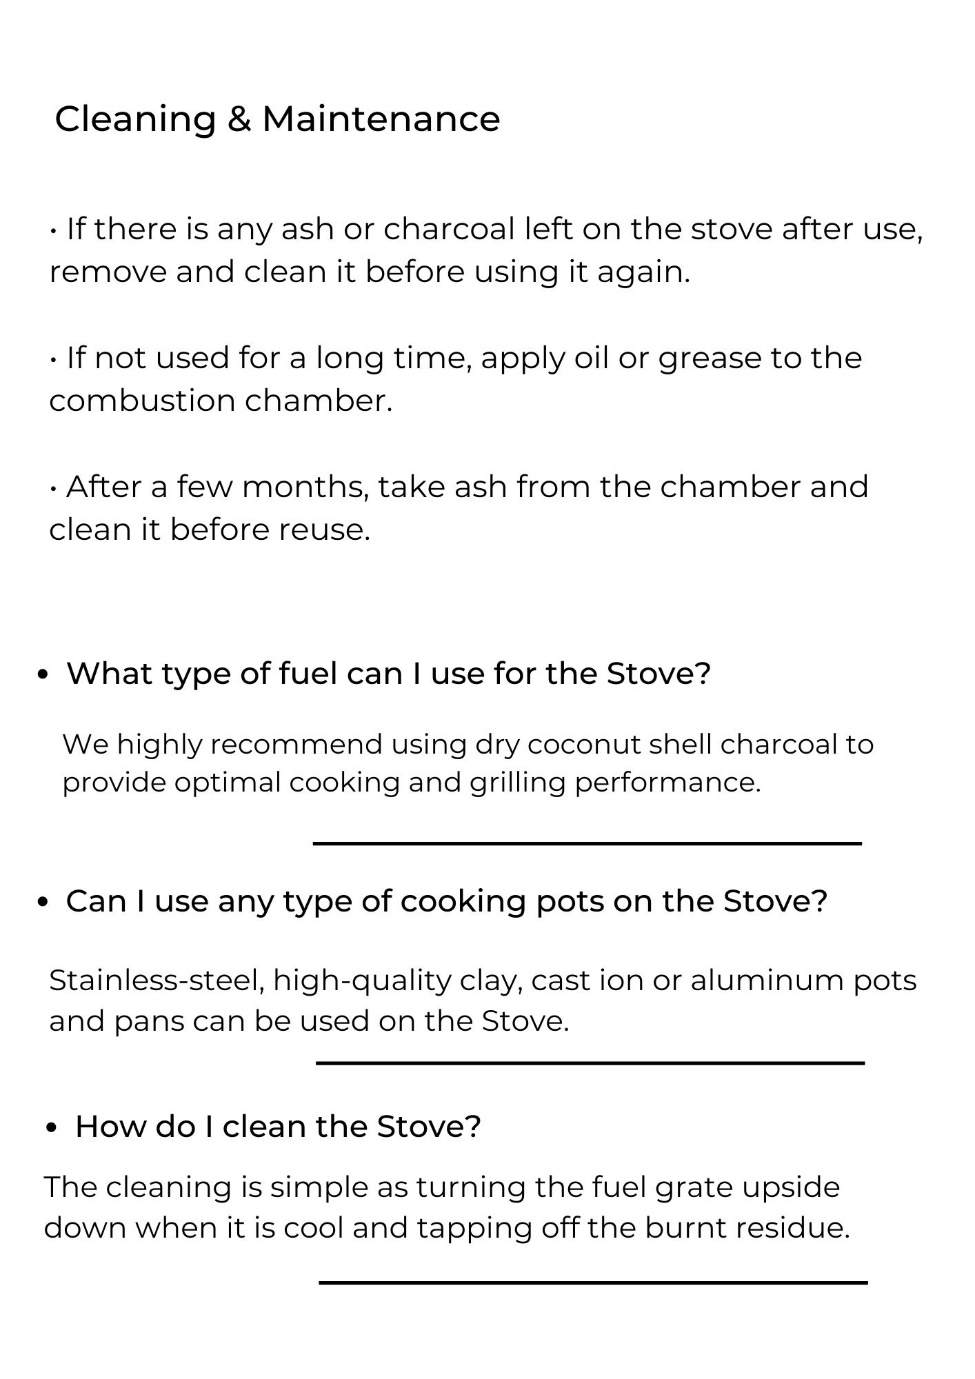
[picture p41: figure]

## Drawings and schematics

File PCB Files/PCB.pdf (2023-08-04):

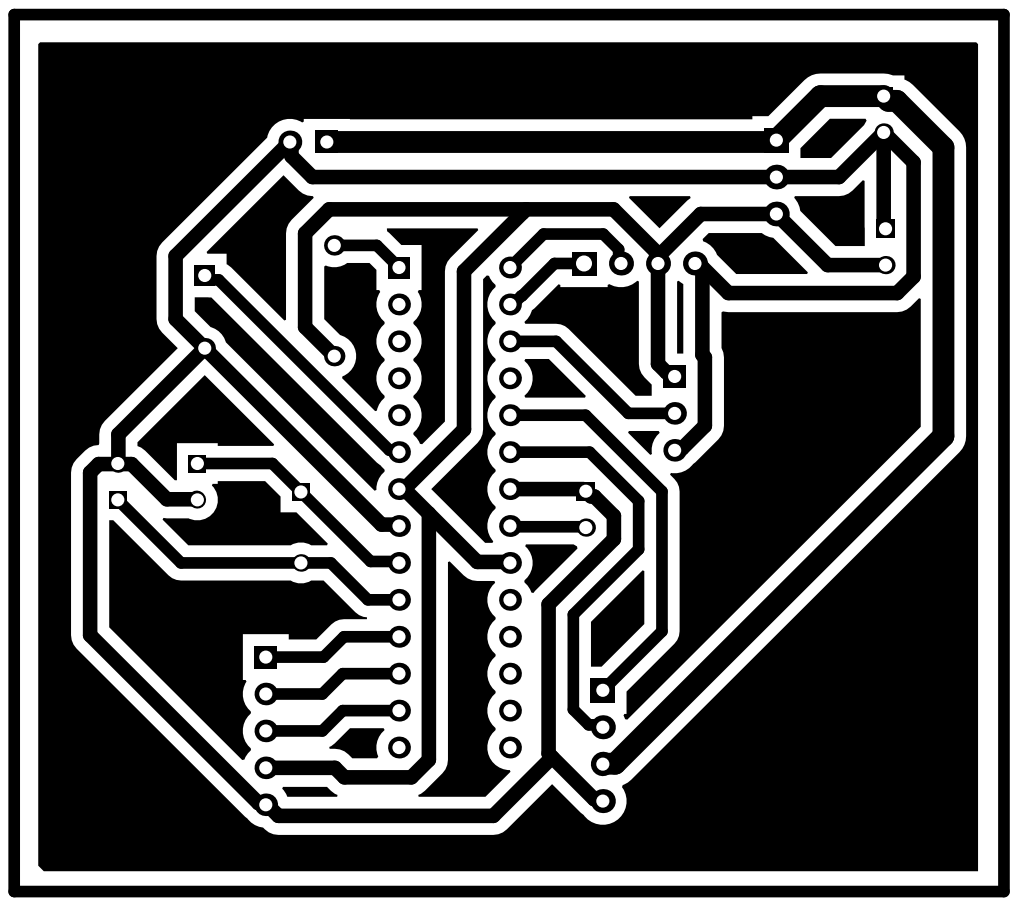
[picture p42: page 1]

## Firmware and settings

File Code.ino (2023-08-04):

#include "max6675.h" // max6675.h file is part of the library that you should download from Robojax.com
#include <Wire.h>
#include <Adafruit_GFX.h>
#include <Adafruit_SSD1306.h>

#define SCREEN_WIDTH 128 // OLED display width, in pixels
#define SCREEN_HEIGHT 64 // OLED display height, in pixels

// Declaration for an SSD1306 display connected to I2C (SDA, SCL pins)
Adafruit_SSD1306 display(SCREEN_WIDTH, SCREEN_HEIGHT, &Wire, -1);

int soPin = 5;// SO=Serial Out
int csPin = 6;// CS = chip select CS pin
int sckPin = 7;// SCK = Serial Clock pin
int analogPin = A3; 
int celTemp;
int tempSet;
int fanPin1 = A1;
int fanPin2 = A0;
int T1;
int T2;
MAX6675 robojax(sckPin, csPin, soPin);// create instance object of MAX6675
bool prevLower = false; // keep track of whether temperature was outside range in previous iteration of loop
bool prevHigher = false;
int prevCount = 0; // keep track of iterations where temperature was below or above range consecutively
String prev_disp;

void setup() {

  pinMode(analogPin, INPUT);
  pinMode(fanPin1, OUTPUT);
  pinMode(fanPin2, OUTPUT);        
  Serial.begin(9600);// initialize serial monitor with 9600 baud
  Serial.println("Robojax MAX6675"); 

  if(!display.begin(SSD1306_SWITCHCAPVCC, 0x3C)) { // Address 0x3D for 128x64
    Serial.println(F("SSD1306 allocation failed"));
    for(;;);
  }
  delay(2000);
  display.clearDisplay();

  display.setTextSize(1.5);
  display.setTextColor(WHITE);
  display.setCursor(30, 10);
  display.println("   HELLO   ");
  display.display();
  prev_disp = "   HELLO   ";
}

void disp(String txt1,String txt2){  //OLED Display Function
  if(txt1!=txt2){
    display.setCursor(30, 10);
    display.setTextColor(BLACK);
    display.println(txt2);
    display.display();
    display.setCursor(30,10);
    display.setTextColor(WHITE);
    display.println(txt1);
    display.display();
  }
}

void loop() {
  // basic readout test, just print the current temp
  // Robojax.com MAX6675 Temperature reading on Serial monitor
   celTemp=robojax.readCelsius();
   tempSet=analogRead(analogPin);
   Serial.print("C = "); 
   Serial.print(celTemp);
   //Serial.print(" C = ");
   //Serial.println(robojax.readCelsius());
   Serial.print(" Controller= ");
   Serial.print(tempSet);

 //celTemp = 200;

   if(tempSet<200){
    T1 = 50;
    T2 = 120; 
    disp("     LOW   ",prev_disp);
    prev_disp = "     LOW   ";
   }else if(tempSet<300){
    T1 = 120;
    T2 = 150;
    disp(" MEDIUM LOW",prev_disp);
    prev_disp = " MEDIUM LOW";
   }else if(tempSet<400){
    T1 = 150;
    T2 = 190;
    disp("  MEDIUM   ",prev_disp);
    prev_disp = "  MEDIUM   ";
   }else if(tempSet<500){
    T1 = 190;
    T2 = 231;
    disp("MEDIUM HIGH",prev_disp);
    prev_disp = "MEDIUM HIGH";
   }else if(tempSet<600){
    T1 = 231;
    T2 = 288;
    disp("    HIGH   ",prev_disp);
    prev_disp = "    HIGH   ";
   }else if(tempSet<700){
    T1 = 288;
    T2 = 372;
    disp(" VERY HIGH ",prev_disp); 
    prev_disp = " VERY HIGH ";
   }

   if(celTemp<T1){
    analogWrite(fanPin1,0);
    analogWrite(fanPin2,255);
    if (prevLower) {
         prevCount++;
      } else {
        prevLower = true;
        prevHigher = false;
        prevCount = 1;
      }
   }else if(celTemp<T2){
    analogWrite(fanPin1,0);
    analogWrite(fanPin2,140);
    prevCount = 0;
    prevLower = false;
    prevHigher = false;
   }else{
    analogWrite(fanPin1,0);
    analogWrite(fanPin2,0);
    if (prevHigher) {
         prevCount++;
      } else {
        prevLower = false;
        prevHigher = true;
        prevCount = 1;
      }
   }

   if (prevCount > 600) { // if temperature has consecutively been lower or higher for n number of iterations then do something
      
    tone(4,255);
    display.setTextColor(WHITE);
    display.setCursor(30, 20);
    display.println("   ERROR   ");
    display.display();
    }
  else{
    display.setTextColor(BLACK);
    display.setCursor(30, 20);
    display.println("   ERROR   ");
    display.display();
    noTone(4);
    }

  Serial.print("\n loop");
  Serial.print(prevCount);
  Serial.print(prevLower);
  Serial.print(prevHigher);   
             
   delay(1000);
}

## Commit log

2023-08-04 PCB files
    [PCB3.step, PCB_Hearth.PcbDoc, PCB_Project_Hearth.PrjPcb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]
2023-08-04 Solidworks Files
    [80MM_FAN.step, Box.SLDPRT, COAL.SLDPRT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]
